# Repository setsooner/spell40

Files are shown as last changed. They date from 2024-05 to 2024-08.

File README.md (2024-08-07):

<div align=center>
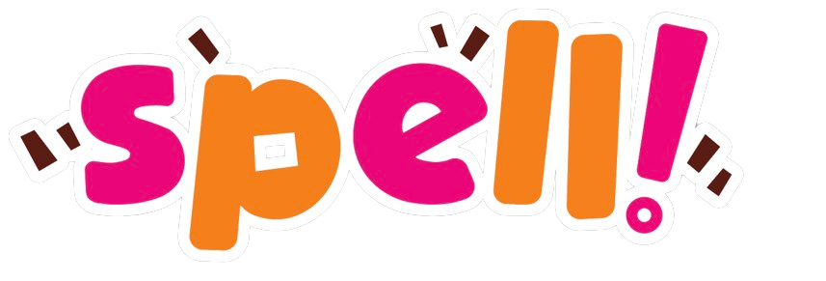
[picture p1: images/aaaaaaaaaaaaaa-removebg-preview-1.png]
  
</div>

---

<h4 align="center">A megumin themed 40% (but not really) keyboard.</h4>
<div align="center">
  Spell-Test-3
</div>

## Intro
hello! spell40 is a 40% keyboard with a layout reminiscent of the W1-AT. It was designed by me and my friend binb0y of mkh. The board utlizes tadpole + gummy oring mounts, and a 6.2deg typing angle. The engravings (and general design, to an extent) are inspired by konosuba! character megumin. The layout is inspired by both the W1-AT, as well as the mkh studio bully. We took the numpad and xt from the W1 and attached it to the 13.5u width of the bully, with completely different bottom row support. The board should be compatible with the majority of base kits, given it includes the numpad. 

As of time of writing, prototype 1 has been received, and faults in the design have been found and remedied. A second prototype run is in the works. Hotswap pcb is basically done, but I will not be posting it until I've verified it works.

## Required Components
* Daughterboard
  * spell is designed to use any C series daughterboard, but the 3D model of [this](https://github.com/Unified-Daughterboard/UDB-C-JSH) was what I used while modeling.
* Mounting
  * spell mounts with either 9 GEON tadpoles, or with an o-ring. O-ring specs are 3.5mm CS x 200m ID. O-ring of 192mm has been tested and verified to work. TKL orings also work.
  * [Tadpoles](https://geon.works/products/tadpole)
  * [Where we're getting our o-ring](https://www.polymax.co.uk/o-rings/rubber-silicone-o-rings/)
* Screws
  * Case screws are M2x8mm, daughterboard screws are M2x4mm.
* PCB
  * TODO: put text here.
* Case Feet
  * spell uses [SKUF feet](https://github.com/Zambumon/SKUF).

## Special Thanks 
While I say me and binb0y designed this, it took a lot of help from the community to get here. I'd like to extend my thanks to chill for his invaluable PCB advice. zhol and paaradiso of mkh for general design advice for everything from pcbs to the specifics of bottom case engravings. GEON for some pointers on mounting point placement. Cute for making amazing renders, and everyone else in MechKeys who contributed their opinions and for dealing with our constant pestering over the 1.5 years it took for the project to get here.

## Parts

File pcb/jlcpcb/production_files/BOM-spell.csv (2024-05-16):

Comment | Designator | Footprint | LCSC
10n | C9 | C_0402_1005Metric | C15195
4.7u | C4 | C_0402_1005Metric | C23733
10k | R1 | R_0603_1608Metric | C25804
JST SH 4p | J1 | JST_SH_SM04B-SRSS-TB_1x04-1MP_P1.00mm_Horizontal | C2845363
100n | C1,C5,C6,C7,C8 | C_0402_1005Metric | C307331
RST | SW1,SW2 | SW_SPST_TL3342 | C318884
1u | C10,C2,C3 | C_0402_1005Metric | C52923
XC6206PxxxMR | U2 | SOT-23-3 | C5446
D | D1,D10,D11,D12,D13,D14,D15,D16,D17,D18,D19,D2,D20,D21,D22,D23,D24,D25,D26,D27,D28,D29,D3,D30,D31,D32,D33,D34,D35,D36,D37,D38,D39,D4,D40,D41,D42,D43,D44,D45,D46,D47,D48,D49,D5,D51,D52,D53,D54,D55,D56,D57,D58,D59,D6,D60,D61,D62,D63,D64,D65,D66,D67,D68,D69,D7,D8,D9 | D_SOD-123 | C7420318
STM32F072CBTx | U1 | LQFP-48_7x7mm_P0.5mm | C915660

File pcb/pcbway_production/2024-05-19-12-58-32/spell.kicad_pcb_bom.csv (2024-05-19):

designator | quantity | value | pack | mpn | mount_type
, , , , , , , | 8 |  |  |  | tht
C1, C5, C6, C7, C8 | 5 | 100n | C_0402_1005Metric |  | smt
C10, C2, C3 | 3 | 1u | C_0402_1005Metric |  | smt
C4 | 1 | 4.7u | C_0402_1005Metric |  | smt
C9 | 1 | 10n | C_0402_1005Metric |  | smt
D1, D10, D11, D12, D13, D14, D15, D16, D17, D18, D19, D2, D20, D21, D22, D23, D24, D25, D26, D27, D28, D29, D3, D30, D31, D32, D33, D34, D35, D36, D37, D38, D39, D4, D40, D41, D42, D43, D44, D45, D46, D47, D48, D49, D5, D51, D52, D53, D54, D55, D56, D57, D58, D59, D6, D60, D61, D62, D63, D64, D65, D66, D67, D68, D69, D7, D8, D9 | 68 | D | D_SOD-123 |  | smt
J1 | 1 | JST SH 4p | JST_SH_SM04B-SRSS-TB_1x04-1MP_P1.00mm_Horizontal |  | smt
MX1 | 1 | F1 | SW_MX_1u |  | tht
MX10 | 1 | U | SW_MX_1u |  | tht
MX11 | 1 | I | SW_MX_1u |  | tht
MX12 | 1 | O | SW_MX_1u |  | tht
MX13 | 1 | P | SW_MX_1u |  | tht
MX14 | 1 | [ | SW_MX_1u |  | tht
MX15 | 1 | ] | SW_MX_1u |  | tht
MX16 | 1 | BS | SW_MX_1u |  | tht
MX17 | 1 | 7 | SW_MX_1u |  | tht
MX18 | 1 | 8 | SW_MX_1u |  | tht
MX19 | 1 | 9 | SW_MX_1u |  | tht
MX2 | 1 | F5 | SW_MX_1u |  | tht
MX20 | 1 | F2 | SW_MX_1u |  | tht
MX21 | 1 | F6 | SW_MX_1u |  | tht
MX22 | 1 | CL | SW_MX_1.75u |  | tht
MX23 | 1 | A | SW_MX_1u |  | tht
MX24 | 1 | S | SW_MX_1u |  | tht
MX25 | 1 | D | SW_MX_1u |  | tht
MX26 | 1 | F | SW_MX_1u |  | tht
MX27 | 1 | G | SW_MX_1u |  | tht
MX28 | 1 | H | SW_MX_1u |  | tht
MX29 | 1 | J | SW_MX_1u |  | tht
MX3 | 1 | TAB | SW_MX_1.5u |  | tht
MX30 | 1 | K | SW_MX_1u |  | tht
MX31 | 1 | L | SW_MX_1u |  | tht
MX32 | 1 | ; | SW_MX_1u |  | tht
MX33 | 1 | Enter | SW_MX_1.75u |  | tht
MX34 | 1 | 4 | SW_MX_1u |  | tht
MX35 | 1 | 5 | SW_MX_1u |  | tht
MX36 | 1 | 6 | SW_MX_1u |  | tht
MX37 | 1 | F3 | SW_MX_1u |  | tht
MX38 | 1 | F7 | SW_MX_1u |  | tht
MX39 | 1 | LS | SW_MX_1u |  | tht
MX4 | 1 | Q | SW_MX_1u |  | tht
MX40 | 1 | Z | SW_MX_1u |  | tht
MX41 | 1 | X | SW_MX_1u |  | tht
MX42 | 1 | C | SW_MX_1u |  | tht
MX43 | 1 | V | SW_MX_1u |  | tht
MX44 | 1 | B | SW_MX_1u |  | tht
MX45 | 1 | N | SW_MX_1u |  | tht
MX46 | 1 | M | SW_MX_1u |  | tht
MX47, MX65, MX66 | 3 | . | SW_MX_1u |  | tht
MX48 | 1 | , | SW_MX_1u |  | tht
MX49 | 1 | / | SW_MX_1u |  | tht
MX5 | 1 | W | SW_MX_1u |  | tht
MX50 | 1 | Shift 1.25 | SW_MX_1.25u |  | tht
MX51 | 1 | Shift 2.25u | SW_MX_1u |  | tht
MX52 | 1 | 1 | SW_MX_1u |  | tht
MX53 | 1 | 2 | SW_MX_1u |  | tht
MX54 | 1 | 3 | SW_MX_1u |  | tht
MX55 | 1 | F4 | SW_MX_1u |  | tht
MX56 | 1 | F8 | SW_MX_1u |  | tht
MX57 | 1 | CTRL 1u | SW_MX_1u |  | tht
MX58, MX61 | 2 | GUI 1.25u | SW_MX_1.25u |  | tht
MX59 | 1 | 1u alt | SW_MX_1u |  | tht
MX6 | 1 | E | SW_MX_1u |  | tht
MX60 | 1 | alt 1u | SW_MX_1u |  | tht
MX62 | 1 | 1u ctrl | SW_MX_1u |  | tht
MX63 | 1 | 0 | SW_MX_1u |  | tht
MX64 | 1 | 2u 0 | SW_MX_1u |  | tht
MX67 | 1 | alt 1.50u | SW_MX_1.5u |  | tht
MX68, MX71 | 2 | GUI 1u | SW_MX_1u |  | tht
MX69 | 1 | 1.25 ctrl | SW_MX_1.25u |  | tht
MX7 | 1 | R | SW_MX_1u |  | tht
MX70 | 1 | CTRL 1.25u | SW_MX_1.25u |  | tht
MX72 | 1 | 1.5u alt | SW_MX_1.5u |  | tht
MX73 | 1 | L 1u split sb | SW_MX_1u |  | tht
MX74 | 1 | S 7u 2.25 | SW_MX_1u |  | tht
MX75 | 1 | 7u & centered 6u | SW_MX_1u |  | tht
MX76 | 1 | S 7u 2.75 | SW_MX_1u |  | tht
MX77 | 1 | R 1u split sb | SW_MX_1u |  | tht
MX78, MX80 | 2 | S 6u 2.25 | SW_MX_1u |  | tht
MX79 | 1 | 1u 6u split | SW_MX_1u |  | tht
MX8 | 1 | T | SW_MX_1u |  | tht
MX81 | 1 | CL | SW_MX_1.25u |  | tht
MX9 | 1 | Y | SW_MX_1u |  | tht
R1 | 1 | 10k | R_0603_1608Metric |  | smt
S1, S2 | 2 | 2u | STAB_MX_2u |  | tht
S10 | 1 | 6u | STAB_MX_6u |  | tht
S11, S12, S3, S7 | 4 | 2.25 | STAB_MX_2.25u |  | tht
S5, S8 | 2 | 2.75 | STAB_MX_2.75u |  | tht
S9 | 1 | 7u | STAB_MX_7u |  | tht
SW1 | 1 | RST | SW_SPST_TL3342 |  | smt
SW2 | 1 | BOOT | SW_SPST_TL3342 |  | smt
U1 | 1 | STM32F072CBTx | LQFP-48_7x7mm_P0.5mm |  | smt
U2 | 1 | XC6206PxxxMR | SOT-23-3 |  | smt

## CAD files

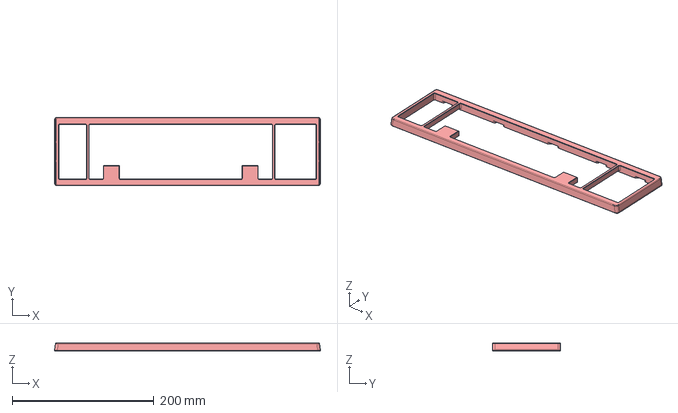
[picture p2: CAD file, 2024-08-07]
case/spell wkl top_.step
374.9 x 96.1 x 11.0 mm

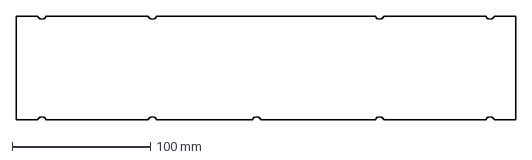
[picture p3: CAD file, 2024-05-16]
pcb/edge cut 2.dxf
360.8 x 75.1 mm

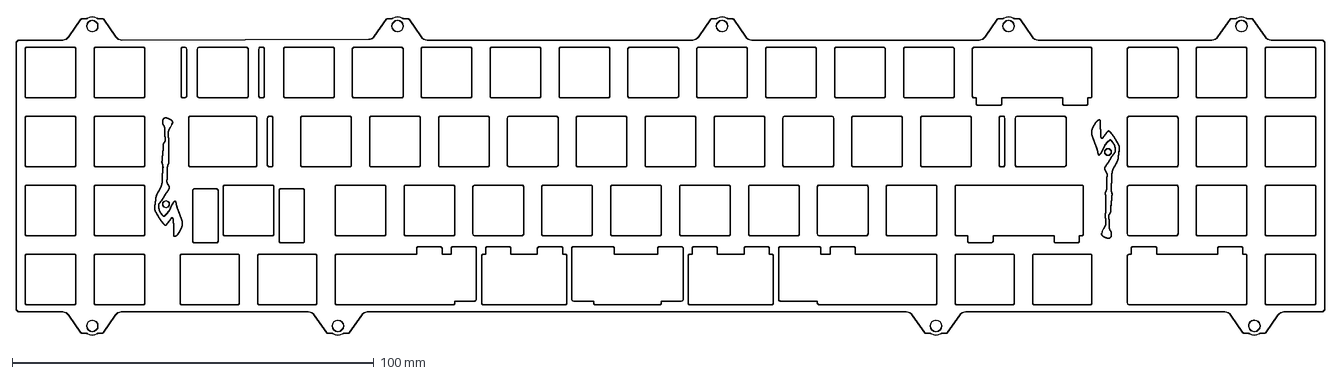
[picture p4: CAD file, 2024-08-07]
plate/spell plate proto r2.dxf
362.0 x 88.3 mm

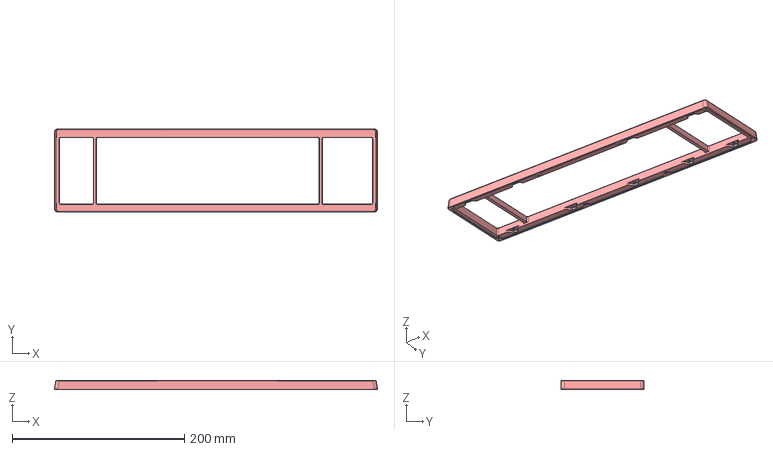
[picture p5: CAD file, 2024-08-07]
case/spell top wk.step
374.9 x 96.1 x 11.0 mm

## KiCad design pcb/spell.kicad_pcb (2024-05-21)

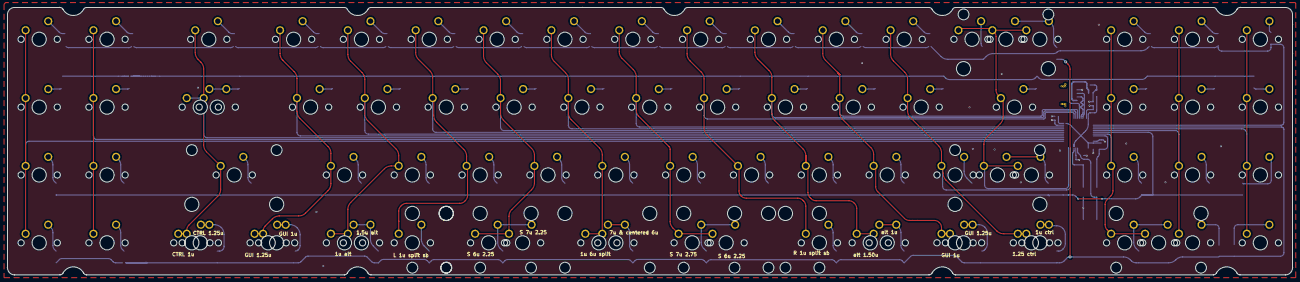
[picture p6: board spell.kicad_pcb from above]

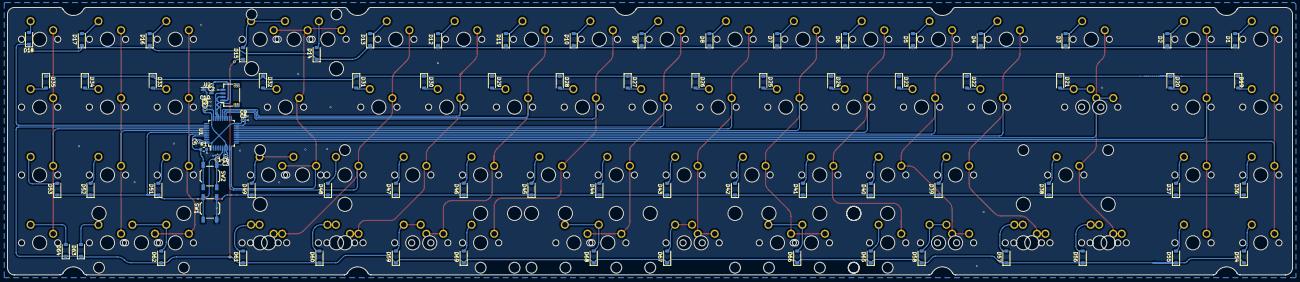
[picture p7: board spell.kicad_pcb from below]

Board: 2 copper layers, 360.8 x 75.1 mm, 175 parts (84 on the bottom side), 96 nets.

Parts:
C1, C5, C6, C7, C8: 100n; C_0402_1005Metric
C2, C3, C10: 1u; C_0402_1005Metric
C4: 4.7u; C_0402_1005Metric
C9: 10n; C_0402_1005Metric
D1, D2, D3, D4, D5, D6, D7, D8, D9, D10, D11, D12, D13, D14, D15, D16, D17, D18, D19, D20, D21, D22, D23, D24, D25, D26, D27, D28, D29, D30, D31, D32, D33, D34, D35, D36, D37, D38, D39, D40, D41, D42, D43, D44, D45, D46, D47, D48, D49, D51, D52, D53, D54, D55, D56, D57, D58, D59, D60, D61, D62, D63, D64, D65, D66, D67, D68, D69: D; D_SOD-123
J1: JST SH 4p; JST_SH_SM04B-SRSS-TB_1x04-1MP_P1.00mm_Horizontal
MX1: F1; SW_MX_1u
MX2: F5; SW_MX_1u
MX3: TAB; SW_MX_1.5u
MX4: Q; SW_MX_1u
MX5: W; SW_MX_1u
MX6: E; SW_MX_1u
MX7: R; SW_MX_1u
MX8: T; SW_MX_1u
MX9: Y; SW_MX_1u
MX10: U; SW_MX_1u
MX11: I; SW_MX_1u
MX12: O; SW_MX_1u
MX13: P; SW_MX_1u
MX14: [; SW_MX_1u
MX15: ]; SW_MX_1u
MX16: BS; SW_MX_1u
MX17: 7; SW_MX_1u
MX18: 8; SW_MX_1u
MX19: 9; SW_MX_1u
MX20: F2; SW_MX_1u
MX21: F6; SW_MX_1u
MX22: CL; SW_MX_1.75u
MX23: A; SW_MX_1u
MX24: S; SW_MX_1u
MX25: D; SW_MX_1u
MX26: F; SW_MX_1u
MX27: G; SW_MX_1u
MX28: H; SW_MX_1u
MX29: J; SW_MX_1u
MX30: K; SW_MX_1u
MX31: L; SW_MX_1u
MX32: ;; SW_MX_1u
MX33: Enter; SW_MX_1.75u
MX34: 4; SW_MX_1u
MX35: 5; SW_MX_1u
MX36: 6; SW_MX_1u
MX37: F3; SW_MX_1u
MX38: F7; SW_MX_1u
MX39: LS; SW_MX_1u
MX40: Z; SW_MX_1u
MX41: X; SW_MX_1u
MX42: C; SW_MX_1u
MX43: V; SW_MX_1u
MX44: B; SW_MX_1u
MX45: N; SW_MX_1u
MX46: M; SW_MX_1u
MX47, MX65, MX66: .; SW_MX_1u
MX48: ,; SW_MX_1u
MX49: /; SW_MX_1u
MX50: Shift 1.25; SW_MX_1.25u
MX51: Shift 2.25u; SW_MX_1u
MX52: 1; SW_MX_1u
MX53: 2; SW_MX_1u
MX54: 3; SW_MX_1u
MX55: F4; SW_MX_1u
MX56: F8; SW_MX_1u
MX57: CTRL 1u; SW_MX_1u
MX58, MX61: GUI 1.25u; SW_MX_1.25u
MX59: 1u alt; SW_MX_1u
MX60: alt 1u; SW_MX_1u
MX62: 1u ctrl; SW_MX_1u
MX63: 0; SW_MX_1u
MX64: 2u 0; SW_MX_1u
MX67: alt 1.50u; SW_MX_1.5u
MX68, MX71: GUI 1u; SW_MX_1u
MX69: 1.25 ctrl; SW_MX_1.25u
MX70: CTRL 1.25u; SW_MX_1.25u
MX72: 1.5u alt; SW_MX_1.5u
MX73: L 1u split sb; SW_MX_1u
MX74: S 7u 2.25; SW_MX_1u
MX75: 7u & centered 6u; SW_MX_1u
MX76: S 7u 2.75; SW_MX_1u
MX77: R 1u split sb; SW_MX_1u
MX78, MX80: S 6u 2.25; SW_MX_1u
MX79: 1u 6u split; SW_MX_1u
MX81: CL; SW_MX_1.25u
R1: 10k; R_0603_1608Metric
S1, S2: 2u; STAB_MX_2u
S3, S7, S11, S12: 2.25; STAB_MX_2.25u
S5, S8: 2.75; STAB_MX_2.75u
S9: 7u; STAB_MX_7u
S10: 6u; STAB_MX_6u
SW1: RST; SW_SPST_TL3342
SW2: BOOT; SW_SPST_TL3342
U1: STM32F072CBTx; LQFP-48_7x7mm_P0.5mm
U2: XC6206PxxxMR; SOT-23-3

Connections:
+3V3: C3.1, C4.1, C5.1, C6.1, C7.1, C8.1, C9.1, C10.1, SW2.1, U1.1 (VBAT), U1.9 (VDDA), U1.24 (VDD), U1.36 (VDDIO2), U1.48 (VDD), U2.2 (VO)
+5V: C2.1, J1.1, U2.3 (VI)
BOOT0: R1.1, SW2.2, U1.44 (BOOT0)
COL01: MX1.1, MX20.1, MX37.1, MX55.1, U1.14 (PA4)
COL02: MX2.1, MX21.1, MX38.1, MX56.1, U1.15 (PA5)
COL03: MX3.1, MX22.1, MX39.1, MX57.1, MX70.1, MX81.1, U1.16 (PA6)
COL04: MX4.1, MX23.1, MX40.1, MX58.1, MX71.1, U1.17 (PA7)
COL05: MX5.1, MX24.1, MX41.1, MX59.1, MX72.1, U1.18 (PB0)
COL06: MX6.1, MX25.1, MX42.1, MX73.1, U1.19 (PB1)
COL07: MX7.1, MX26.1, MX43.1, MX74.1, MX78.1, U1.20 (PB2)
COL08: MX8.1, MX27.1, MX44.1, MX75.1, MX79.1, U1.21 (PB10)
COL09: MX9.1, MX28.1, MX45.1, MX76.1, MX80.1, U1.22 (PB11)
COL10: MX10.1, MX29.1, MX46.1, MX77.1, U1.28 (PB15)
COL11: MX11.1, MX30.1, MX47.1, MX60.1, MX67.1, U1.29 (PA8)
COL12: MX12.1, MX31.1, MX48.1, MX61.1, MX68.1, U1.30 (PA9)
COL13: MX13.1, MX32.1, MX49.1, MX62.1, MX69.1, U1.11 (PA1)
COL14: MX14.1, MX15.1, MX16.1, MX33.1, MX50.1, MX51.1, U1.12 (PA2)
COL15: MX17.1, MX34.1, MX52.1, MX63.1, MX64.1, U1.43 (PB7)
COL16: MX18.1, MX35.1, MX53.1, MX65.1, U1.41 (PB5)
COL17: MX19.1, MX36.1, MX54.1, MX66.1, U1.40 (PB4)
D+: J1.3, U1.33 (PA12)
D-: J1.2, U1.32 (PA11)
GND: C1.2, C2.2, C3.2, C4.2, C5.2, C6.2, C7.2, C8.2, C9.2, C10.2, J1.4, R1.2, SW1.2, U1.8 (VSSA), U1.23 (VSS), U1.35 (VSS), U1.47 (VSS), U2.1 (GND)
unnamed: D1.2 (A), MX1.2
unnamed: D2.2 (A), MX2.2
unnamed: D3.2 (A), MX3.2
unnamed: D4.2 (A), MX4.2
unnamed: D5.2 (A), MX5.2
unnamed: D6.2 (A), MX6.2
unnamed: D7.2 (A), MX7.2
unnamed: D8.2 (A), MX8.2
unnamed: D9.2 (A), MX9.2
unnamed: D10.2 (A), MX10.2
unnamed: D11.2 (A), MX11.2
unnamed: D12.2 (A), MX12.2
unnamed: D13.2 (A), MX13.2
unnamed: D14.2 (A), MX14.2
unnamed: D15.2 (A), MX15.2, MX16.2
unnamed: D16.2 (A), MX17.2
unnamed: D17.2 (A), MX18.2
unnamed: D18.2 (A), MX19.2
unnamed: D19.2 (A), MX20.2
unnamed: D20.2 (A), MX21.2
unnamed: D21.2 (A), MX22.2, MX81.2
unnamed: D22.2 (A), MX23.2
unnamed: D23.2 (A), MX24.2
unnamed: D24.2 (A), MX25.2
unnamed: D25.2 (A), MX26.2
unnamed: D26.2 (A), MX27.2
unnamed: D27.2 (A), MX28.2
unnamed: D28.2 (A), MX29.2
unnamed: D29.2 (A), MX30.2
unnamed: D30.2 (A), MX31.2
unnamed: D31.2 (A), MX32.2
unnamed: D32.2 (A), MX33.2
unnamed: D33.2 (A), MX34.2
unnamed: D34.2 (A), MX35.2
unnamed: D35.2 (A), MX36.2
unnamed: D36.2 (A), MX37.2
unnamed: D37.2 (A), MX38.2
unnamed: D38.2 (A), MX39.2
unnamed: D39.2 (A), MX40.2
unnamed: D40.2 (A), MX41.2
unnamed: D41.2 (A), MX42.2
unnamed: D42.2 (A), MX43.2
unnamed: D43.2 (A), MX44.2
unnamed: D44.2 (A), MX45.2
unnamed: D45.2 (A), MX46.2
unnamed: D46.2 (A), MX47.2
unnamed: D47.2 (A), MX48.2
unnamed: D48.2 (A), MX49.2
unnamed: D49.2 (A), MX50.2, MX51.2
unnamed: D51.2 (A), MX52.2
unnamed: D52.2 (A), MX53.2
unnamed: D53.2 (A), MX54.2
unnamed: D54.2 (A), MX55.2
unnamed: D55.2 (A), MX56.2
unnamed: D56.2 (A), MX57.2, MX70.2
unnamed: D57.2 (A), MX58.2, MX71.2
unnamed: D58.2 (A), MX59.2, MX72.2
unnamed: D59.2 (A), MX60.2, MX67.2
unnamed: D60.2 (A), MX61.2, MX68.2
unnamed: D61.2 (A), MX62.2, MX69.2
unnamed: D62.2 (A), MX63.2, MX64.2
unnamed: D63.2 (A), MX65.2
unnamed: D64.2 (A), MX66.2
unnamed: D65.2 (A), MX73.2
unnamed: D66.2 (A), MX74.2, MX78.2
unnamed: D67.2 (A), MX75.2, MX79.2
unnamed: D68.2 (A), MX76.2, MX80.2
unnamed: D69.2 (A), MX77.2
ROW1: D1.1 (K), D2.1 (K), D3.1 (K), D4.1 (K), D5.1 (K), D6.1 (K), D7.1 (K), D8.1 (K), D9.1 (K), D10.1 (K), D11.1 (K), D12.1 (K), D13.1 (K), D14.1 (K), D16.1 (K), D17.1 (K), D18.1 (K), U1.38 (PA15)
ROW2: D19.1 (K), D20.1 (K), D21.1 (K), D22.1 (K), D23.1 (K), D24.1 (K), D25.1 (K), D26.1 (K), D27.1 (K), D28.1 (K), D29.1 (K), D30.1 (K), D31.1 (K), D32.1 (K), D33.1 (K), D34.1 (K), D35.1 (K), U1.31 (PA10)
ROW3: D36.1 (K), D37.1 (K), D38.1 (K), D39.1 (K), D40.1 (K), D41.1 (K), D42.1 (K), D43.1 (K), D44.1 (K), D45.1 (K), D46.1 (K), D47.1 (K), D48.1 (K), D49.1 (K), D51.1 (K), D52.1 (K), D53.1 (K), U1.42 (PB6)
ROW4: D15.1 (K), D54.1 (K), D55.1 (K), D56.1 (K), D57.1 (K), D58.1 (K), D59.1 (K), D60.1 (K), D61.1 (K), D62.1 (K), D63.1 (K), D64.1 (K), D65.1 (K), D66.1 (K), D67.1 (K), D68.1 (K), D69.1 (K), U1.39 (PB3)
~RST: C1.1, SW1.1, U1.7 (NRST)

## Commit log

2024-05-16 added pcb stuff
    [BOM-spell.csv, matrix.kicad_sch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]
2024-05-16 added things
    [spell_plate.dxf, top case.step]
2024-05-16 added edge cuts
    [edge cut 2.dxf]
2024-05-19 update to latest
    [matrix.kicad_sch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]
2024-05-19 moar updates
    [BOM-spell.csv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]
2024-07-10 updated files to proto production
    [bottom case - logo free.step, spell plate v2.dxf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]
2024-08-07 updated to match proto r2
    [bottom case.step, spell plate proto r2.dxf, spell plate v2.dxf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]
